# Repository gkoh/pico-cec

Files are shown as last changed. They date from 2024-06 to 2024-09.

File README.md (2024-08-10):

# Pico-CEC

A Raspberry Pi Pico based project to bridge HDMI CEC (Consumer Electronics
Control) and USB HID keyboard control (especially for use with Kodi).

Fully assembled Pico-CEC.

## Motivation

Micro/mini desktops are plentiful as second hand, budget friendly media players,
especially when installed with Kodi (eg. LibreELEC).
However, many of these devices do not support HDMI-CEC and require the user to
use additional peripherals (eg. wireless keyboard, game controller).

In this project we use a Pico to both:
* handle the CEC protocol on the HDMI port
* adapt the user control messages into USB keyboard inputs

## What Works
* HDMI CEC frame send and receive
* EDID parsing to determine HDMI physical address
* LibreELEC recognises Pico-CEC as an USB HID keyboard
* HDMI CEC basic user control messages are properly mapped to Kodi shortcuts,
  including:
   * navigations arrows
   * select
   * back
   * play
   * pause
   * numbers 0-9

## Cloning
To avoid cloning unneeded code, clone like this:
```
git -c submodule.active="lib/tinyusb" -c submodule.active=":(exclude,glob){lib,hw}/*" clone --recurse-submodules
```

Alternatively, clone everything in pico-sdk and tinyUSB:
```
git clone --recurse-submodules
```

## Building
This project uses the 'normal' CMake based build. To build the default image:
```
$ git clone <blah blah as above>
$ cd pico-cec
$ mkdir build && cd build
$ cmake ..
$ make
```

### Customising the Build
The CMake project supports three options:
* PICO_BOARD: specify variant of Pico board, defaults to Seeed XIAO RP2040
* CEC_PIN: specify GPIO pin for HDMI CEC, defaults to GPIO3

Example invocation to specify:
* use Raspberry Pi Pico development board
* use GPIO pin 11

```
$ cmake -DPICO_BOARD=pico -DCEC_PIN=11 ..
$ make
```

## Installing
Assuming a successful build, the build directory will contain `pico-cec.uf2`,
this can be written to the Pico as per normal:
* connect the Pico to computer via USB cable
* reset the Pico by holding 'Boot' and pressing 'Reset'
   * Pico now presents as a USB mass storage device
* copy `pico-cec.uf2` to the Pico
* disconnect

# Real World Usage
This is currently working with:
* a Sharp 60" TV (physical address 0x1000)
   * directly connected to TV HDMI input 1
* through a Denon AVR connected to the Sharp TV (physical address 0x1100)
   * Pico-CEC connected to Denon AVR HDMI input 1
   * Denon AVR connected to TV HDMI input 1
* a Sony 60" TV (physical address 0x1000)
   * directly connected to TV HDMI input 1

# Design
## Hardware
The hardware connections are extremely simple. Both HDMI CEC and the Pico are
3.3V obviating the need for level shifters. The DDC bus (for EDID) is I2C and
5V, however, the Pico appears to be 5V tolerant.

Additionally, we rely on the GPIO input/output impedance states to read or drive
the CEC bus. DDC is I2C requiring data and clock lines.
Thus, we need to directly connect four wires:
* HDMI CEC pin 13 direct to a GPIO
* HDMI CEC ground pin 17 direct to GND
* HDMI DDC clock pin 15 direct to SCL
* HDMI DDC data pin 16 direct to SDA

For the Seeed Studio XIAO RP2040:
* HDMI pin 13 --> D10
* HDMI pin 17 --> GND
* HDMI pin 15 --> D5
* HDMI pin 16 --> D4

### Schematic
Basic schematic.

After this we:
* connect `Pico-CEC` to the HDMI output of the PC
* connect the HDMI cable from the TV to `Pico-CEC`
* connect a USB cable from `Pico-CEC` to the PC

### Prototype

Initial prototype.

### Enclosure
The enclosure is a reasonably simple three piece sandwich 3d print modelled with OpenSCAD. It is designed to be printed as three separate pieces which are bolted together with M3 nuts and bolts.
An exploded preview of the result can be found in this [STL](openscad/pico-cec.stl).

### Assembly
XIAO RP2040 with HDMI pass through and DDC.

Partially assembled Pico-CEC.

## Software
The software is extremely simple and built on FreeRTOS tasks:
* cec_task
   * interact with HDMI CEC sending user control message inputs to a queue
* hid_task
   * read the user control messages from the queue and send to the USB task
* usbd_task
   * generate an HID keyboard input for the USB host
* blink_task
   * heart beat, no blink == no work

## cec_task
The CEC task comprises three major components:
* `recv_frame`
   * receives and validates CEC packets from the CEC GPIO pin
   * edge interrupt driven state machine
      * rewritten from busy wait loop to reduce CPU load
* `send_frame`
   * formats and sends CEC packets on the CEC GPIO pin
   * alarm interrupt driven state machine
      * rewritten from busy wait loop to reduce CPU load
* main control loop
   * manages CEC send and receive

All the HDMI frame handling was rewritten to be hardware/timer interrupt driven
to meet real-time constraints.
Attempts to increase the FreeRTOS tick timer along with busy wait loops were
simply unable to consistently meet the CEC timing windows.

## hid_task and usbd_task

These are simple FreeRTOS tasks effectively taken straight from the TinyUSB
examples.

## Dependencies
This project uses:
* FreeRTOS
* pico-sdk
   * tinyusb

# Hardware
* Seeed Studio XIAO RP2040 (chosen for form factor)
   * https://www.seeedstudio.com/XIAO-RP2040-v1-0-p-5026.html
   * Originally prototyped on the Raspberry Pi Pico board (still works with
     minor build time tweaks)
* HDMI male/female passthrough adapter
   * Listed as 'HDMI Male and Female Test Board MINI Connector with Board PCB
     2.54mm pitch 19/20pin DP HD A Female To Male Adapter Board'
   * Model number: WP-905
   * https://www.aliexpress.com/item/1005004791079117.html
* custom 3d printed housing

# Bill of Materials
| Component | Quantity | Price (June 2024) (AUD) |
| :--- | ---: | ---: |
| Seeed Studio XIAO RP2040 | 1 | 11.50 |
| HDMI male/female adapter | 1 | 4.30 |
| M3x10mm bolt & nut | 2 | 0.16 |
| M3x20mm bolt & nut | 2 | 0.17 |
| Random short wires | 2 | basically free |
| Scunge 3D print from friend | 1 | mostly free |
| Umpteen hours of engineering | 1 | priceless |
| Total | | 16.13 |

## Future
* more blinken LEDs
   * most Pico boards appear to have an RGB LED, use it
   * perhaps:
      * R - FreeRTOS crash handlers?
      * G - HDMI message received?
      * B - HID keyboard message sent?
* pass cec-compliance
   * https://docs.kernel.org/userspace-api/media/cec/cec-intro.html
* survive cec-compliance fuzzing
* port to ESP32?

# References
Inspiration and/or ground work was obtained from the following:
* https://github.com/SzymonSlupik/CEC-Tiny-Pro
* https://github.com/tsowell/avr-hdmi-cec-volume

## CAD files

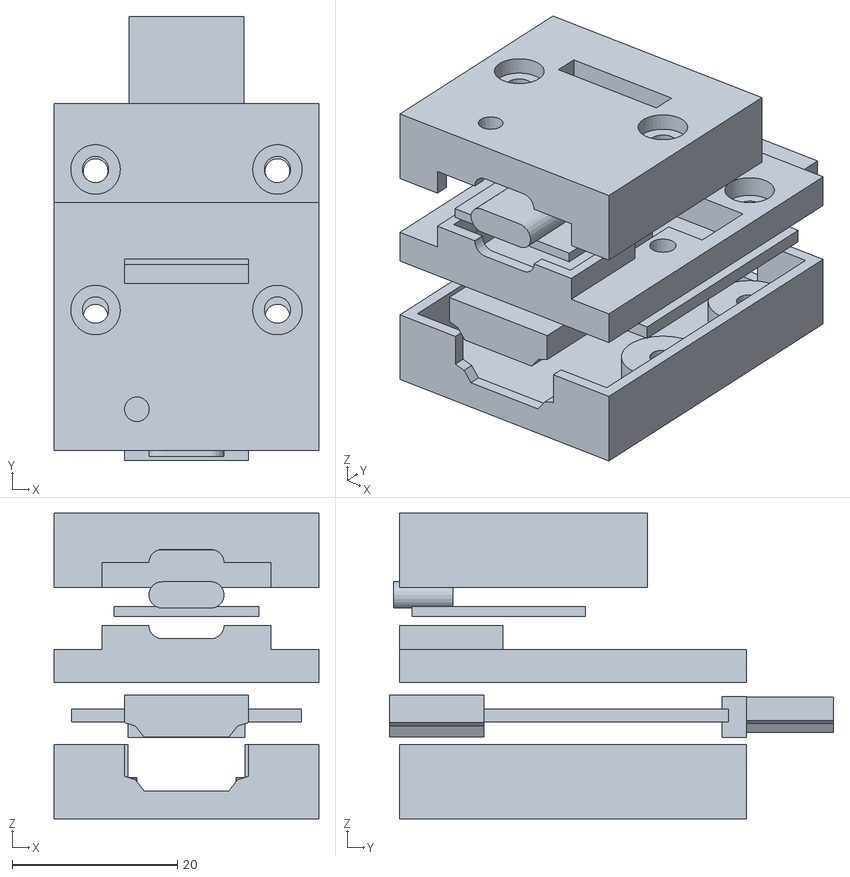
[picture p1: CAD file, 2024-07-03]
openscad/pico-cec.stl
32.0 x 53.7 x 37.0

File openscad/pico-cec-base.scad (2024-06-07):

include <pico-cec-lib.scad>

base();

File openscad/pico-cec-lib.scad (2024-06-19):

$fa = 1;
$fs = $preview ? 2 : 0.5;

module hdmi_2d_male() {
    union () {
        hull() {
            square([13.9, 2.8], true);
                translate([0,-(2.8+0.35)/2])
            square([11.45, 0.35], true);
        }
        hull () {
            translate([0,-(2.8+0.35)/2])
                square([11.45, 0.35], true);
            translate([0, -(4.45)/2])
                square([9.5, 1.3], true);
        }
    }
}

module hdmi_2d_female() {
    scale([15.0/13.9, 5.3/4.45])
        hdmi_2d_male();
}

module hdmi_male() {
    color("goldenrod") union() {
        linear_extrude(12.7)
            hdmi_2d_male();
        translate([0, -1, 12])
            cube([14.2, 5.0, 3],true);
    }
}

module hdmi_female() {
    color("red") linear_extrude(11.4)
        hdmi_2d_female();
}

module hdmi_adapter() {
    union() {
        color("green") difference() {
            cube([27.8, 29.6, 1.6], true);
            translate([11, (29.6/2) - 6, -1.5])
                cylinder(3, r=1.5);
            translate([-11, (29.6/2) - 6, -1.5])
                cylinder(3, r=1.5);
            translate([11, -((29.6/2) - 6), -1.5])
                cylinder(3, r=1.5);
            translate([-11, -((29.6/2) - 6), -1.5])
                cylinder(3, r=1.5);

        }
        translate([0, -(29.6/2), (4.45 - 2.8)/2])
            rotate([90, 0, 0])
                hdmi_female();
        translate([0, (29.6/2) + 12.7, (4.45 - 2.8)/2])
            rotate([90, 0, 0])
                hdmi_male();
    }
}

module usb_c_female() {
    color("silver") linear_extrude(7.2) {
        hull() {
            translate([4.55-1.6, 0, 0])
                circle(r=1.6);
            translate([-4.55+1.6, 0, 0])
                circle(r=1.6);
        }
    }
}

module xiao_rp2040() {
    union() {
        color("blue") cube([17.5, 21.0, 1.2]);
        translate([17.5/2, 5, 1.6+1.0])
            rotate([90,0,0])
                usb_c_female();
    }
}

module nut_m3() {
    cylinder(2.5, r=3.3, $fn=6);
}

module head_m3() {
    cylinder(2.5, r=3);
}

module base() {
    difference() {
        union() {
            difference() {
                cube([32, 40.5+1.5, 9], true);
                translate([0, 0, 1.5])
                    cube([32-3, 40.5+1.5-3, 9-1.5], true);
                translate([0, 4.1, 1.5])
                    hdmi_adapter();
                translate([0, 20, 5])
                    cube([14.1, 3, 3], true);
                translate([0, -20, 5])
                    cube([15.0, 3, 3], true);
            }
            // posts
            translate([11, 13.0, -4.5])
                cylinder(5, r=5);
            translate([11, -4.0, -4.5])
                cylinder(5, r=5);
            translate([-11, 13.0, -4.5])
                cylinder(5, r=5);
            translate([-11, -4.0, -4.5])
                cylinder(5, r=5);
        }
        // bolt
        translate([11, 13.0, -4.55])
            cylinder(5.1, r=1.6);
        translate([11, -4.0, -4.55])
            cylinder(5.1, r=1.6);
        translate([-11, 13.0, -4.55])
            cylinder(5.1, r=1.6);
        translate([-11, -4.0, -4.55])
            cylinder(5.1, r=1.6);
        // nuts
        translate([11, 13.0, -4.55])
            nut_m3();
        translate([11, -4.0, -4.55])
            nut_m3();
        translate([-11, 13.0, -4.55])
            nut_m3();
        translate([-11, -4.0, -4.55])
            nut_m3();
    }
}

module middle() {
    union() {
        difference() {
            cube([32, 40.5+1.5, 4], true);
            // bolt
            translate([11, 13.0, -2.55])
                cylinder(5.1, r=1.6);
            translate([11, -4.0, -2.55])
                cylinder(5.1, r=1.6);
            translate([-11, 13.0, -2.55])
                cylinder(5.1, r=1.6);
            translate([-11, -4.0, -2.55])
                cylinder(5.1, r=1.6);
            // head
            translate([-11, 13.0, -0.45])
                head_m3();
            translate([11, 13.0, -0.45])
                head_m3();
            // xiao rp2040 pins
            translate([7.5, -9.1, 0])
                cube([2.5, 21, 4.05], true);
            translate([-7.5, -9.1, 0])
                cube([2.5, 21, 4.05], true);
            // hdmi adapter pins
            translate([0, 4, 0])
                cube([27.8, 8, 4.05], true);
        }
        // usb-c port bottom half
        translate([0, -20.25, (4+2.9)/2])
            difference() {
                cube([20.5, 1.5, 2.9], true);
                translate([0, 5, 2.9/2 ])
                    rotate([90, 0, 0])
                        usb_c_female();
            }
         // side supports
         translate([-9.6, -14.5, (4+2.9)/2])
            cube([1.3, 12, 2.9], true);
         translate([9.6, -14.5, (4+2.9)/2])
            cube([1.3, 12, 2.9], true);
        }
}

module top() {
    difference() {
        cube([32,30, 9], true);
        translate([0, -2.5, -3])
            cube([32-3, 30-8.5, 9-3], true);
        translate([0, -13.25, -1.5 ])
            rotate([90, 0, 0])
                usb_c_female();
        translate([0, -14.05, -3])
            cube([20.5, 2, 3.05], true);
        // bolt
        translate([-11, 2, -0.5])
            cylinder(5.1, r=1.6);
        translate([11, 2, -0.5])
            cylinder(5.1, r=1.6);
        // head
        translate([-11, 2, 2.5])
            head_m3();
        translate([11, 2, 2.5])
            head_m3();
        // led/button slot
        translate([0, 6.7, 2.2])
            cube([15, 3, 5], true);
        // power led
        translate([-6, -10, -0.3])
            cylinder(5, r=1.5);
    }
}

//base();
//middle();
//top();

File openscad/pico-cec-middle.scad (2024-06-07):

include <pico-cec-lib.scad>

middle();

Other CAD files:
openscad/pico-cec-top.scad
openscad/pico-cec.scad

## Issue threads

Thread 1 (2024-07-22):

Not working with Sony TV

gkoh, 2024-07-22:
Pico-CEC works with a Sharp TV but isn't detected by a Sony TV.
Nothing happens when connected to HDMI port 1 and configured with physical address 0x1000.

Closed 2024-07-22.

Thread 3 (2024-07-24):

Add EDID parsing to determine physical address.

gkoh, 2024-07-24:
The HDMI physical address is available by parsing the EDID data blocks.
This requires adding two more pin connectors (SDA, SCL) to the HDMI DDC lines, these are:
* SDA: HDMI pin 16
* SCL: HDMI pin 15

These should be connected to the RP2040 thus:
* SDA: pin 6
* SCL: pin 7

The I2C bus for DDC is 5V, which is beyond the normal level of the Pico's 3.3V pins. However, directly connecting, despite the voltage difference, works successfully.

Closed 2024-07-26.

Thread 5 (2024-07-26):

Does not work with Samsung TV.

gkoh, 2024-07-26:
Pico-CEC is not detected by a Samsung TV.

Closed 2024-07-28.

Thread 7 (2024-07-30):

Buttons are impossible to access without tools

gkoh, 2024-07-30:
Although the buttons of the XIAO RP2040 are visible, the 3d housing prevents access without either:
* dismantling the enclosure
* using pointed tools (eg. toothpick, small screwdriver)

Possible solutions:
* modify enclosure to expose the buttons for finger pressing
   * remove part of the enclosure?
 * make a button extension thing as part of the enclosure
    * makes assembly a bit fiddly
 * something else?

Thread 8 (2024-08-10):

Display output disrupted on initial boot

gkoh, 2024-08-10:
On initial boot of a Dell Optiplex, the HDMI output is disrupted by `pico-cec`.
I suspect this is due to the DDC/EDID feature, as this didn't occur before.

It seems to be resolved by adding a small (5s) delay to the start of the HDMI CEC task.
This seems long enough for the PC BIOS to work out what display outputs are valid, without `pico-cec` disrupting the DDC traffic.

Closed 2024-08-10.

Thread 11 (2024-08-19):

Extract keymap to file.

dennizzzz, 2024-08-19:
Changing the key mappings requires recompilation. Extracting them to a file would make the system way more flexible.

Example:
```
00, Select, ENTER,
01, Up, ARROW_UP
02, Down, ARROW_DOWN
03, Left, ARROW_LEFT
04, Right, ARROW_RIGHT
0A, Options, C
0D, Exit, BACKSPACE
20, 0, 0
21, 1, 1
22, 2, 2
23, 3, 3
24, 4, 4
25, 5, 5
26, 6, 6
27, 7, 7
28, 8, 8
29, 9, 9
35, Display Information, I
44, Play, P
45, Stop, X
46, Pause, SPACE
48, Rewind, R
49, Fast Forward, F
51, Subtitle, L
```
Thoughts?

gkoh, 2024-08-20:
Interesting suggestion.
How would you envisage this working in:
* development
* installation

Note, this is an embedded system and there is no filesystem right now, so reading a file during runtime would require integrating more stuff.

dennizzzz, 2024-08-20:
> Note, this is an embedded system and there is no filesystem right now, so reading a file during runtime would require integrating more stuff.

My reference before this was a full RPi with Raspbian which has a Linux kernel, filesystems, Kodi and an integrated Pulse-Eight compatible(?) interface.

The absolute best option would be to embed a fat filesystem and a usb-driver and have the board present itself like a regular USB stick. Users write the configuration, including mapping, on it and the system reads it. This would take this project from the developer realm to the consumer realm and could make it a commercial product. (Making it fully Pulse-Eight compatible would also be a giant step in the that direction.)

But for now take a look at [littlefs](https://github.com/littlefs-project/littlefs) or something similar. I have used jffs(2) on my Asus router in the past, but that runs a beefy kernel and has a lot of flash.

gkoh, 2024-08-21:
@dennizzzz Thank you for the considered comment, appreciated.
OK, I think I understand your motivation, allow me to offer some thoughts.

> full RPi with Raspbian

Comparing to such a setup is misleading (but not incorrect). My 'other' HTPC is exactly this and indeed was my reference for what kind of 'experience' to replicate.

> fully Pulse-Eight compatible

The Pulse-Eight HDMI CEC hardware cost is what drove me to create this project. One should note however that it presents as a special USB device requiring driver installation to function. `pico-cec` was deliberately created to emulate an HID keyboard so it would be "plug'n'play", I would like to retain that.
Furthermore, I wonder about possible legal issues with mirroring a commercial product.

> the flexibility of configuration could even make it better

OK, I believe this is the real core of the issue.
Yes, it is inconvenient for an end user to install a full development environment because they want to map, say, 'red' button to the 'backspace'.
As you note, the useful configuration is just the mapping table, and we want to expose that. There are several options:
* present as a USB mass storage device, offer a virtual filesystem and a file defining the mapping
   * this is possible, we can create a virtual FAT filesystem and file and allow the user to edit said file
   * this solution is challenging, it opens up a lot of vectors for instability due to the 'free' nature:
      * user tries to format the device
      * user misconfigures the file
      * user uploads garbage
   * with no UI, we have no way to help the user correct the issue
      * not totally true, we could blink morse code on the LEDs
* present a serial console, offer a basic CLI to show and edit mapping
   * this seems the simplest, the user can open a serial terminal to `pico-cec` and is restricted by what they can do
   * the CLI doesn't need to be complex, all it needs is:
      * show - display the mappings
      * edit - edit/add a mapping entry
         * config can be validated
   * we have text UI now, we can report errors
   * this could even provide the ability to debug the CEC traffic or other aspects
* use a PicoW
   * everything is wifi enable these days
   * we could migrate to PicoW (or ESP32) and present a simple web UI
   * this costs more and requires wifi configuration (eg SSID, key, etc)

My order of preference and ease of implementation:
* USB serial interface
* Pico W + web UI
* USB mass storage + configuration file

Apologies for the long comment, it's a really interesting discussion.
Please let me know if I have misinterpreted anything.

dennizzzz, 2024-08-21:
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

How can MY reference be misleading? To flatten it: a box that work very well with HDMI-CEC.
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

:+1: :+1: :+1: The P8 is becoming rare and so the price is going up even more.

> One should note however that it presents as a special USB device requiring driver installation to function. `pico-cec` was deliberately created to emulate an HID keyboard so it would be "plug'n'play", I would like to retain that. Furthermore, I wonder about possible legal issues with mirroring a commercial product.

The device could be configured the HID-keyboard way (better for Windows) or the P8-driver-compatible way (better for Linux). If the P8 does not have a specific patent then there are no legal grounds for this.

> > the flexibility of configuration could even make it better
>
> OK, I believe this is the real core of the issue. Yes, it is inconvenient for an end user to install a full development environment because they want to map, say, 'red' button to the 'backspace'. As you note, the useful configuration is just the mapping table, and we want to expose that.

:+1:

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

Blink twice ... :smile: .

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

Yes, this could work very well with an ncurses interface. (You duplicated 'serial' here :smile: )

>
>     * Pico W + web UI

Different hardware, big :-1:,  and you would need to configure something to be able to configure something else. But once that is out of the way, writing complex web UI's is part of my day job.
>
>     * USB mass storage + configuration file

This would be easiest for the user, not the developer.

I would like to propose two more options:

1. A dedicated configuration application ("pico-cec-configurator" with a web UI?) that takes a compiled version of pico-cec, lets you configure everything and then flashes the entire thing.
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
gizmomelb, 2024-09-15:
ok found this article about writing to the flash - https://www.makermatrix.com/blog/read-and-write-data-with-the-pi-pico-onboard-flash/

gkoh, 2024-09-15:
> ok found this article about writing to the flash - https://www.makermatrix.com/blog/read-and-write-data-with-the-pi-pico-onboard-flash/

Thanks.
I have an offline branch with basic flash access, so this will certainly be the way forward.

RP2040 flash access requires interrupts to be disabled before access to prevent corruption.
To make it simple and robust I'm thinking to:
* store configuration in flash
* load configuration from flash into RAM during boot
* to reconfigure:
   * create a copy of the running configuration
   * allow user to modify said copy
   * when user saves changes, suspend everything, write copy to flash and require a reboot
      * the CEC task is completely IRQ driven and needs to be stopped before accessing flash

gkoh, 2024-09-15:
> FUTURE STUFF: As an aside - the VCC and GND pins on the underside of the Seeed XAIO RP2040 can be connected to HDMI pins 17 (GND) and 18 (+5V) to continuously power the RP2040 even when it is not drawing power from USB. This could be useful with some extra investigation I am doing with powering down the host pc and using WAKE ON LAN to start it back up - useful for the HDMI CEC power on / power off along with the TV and AVR etc.)

I did originally look into dual-power (VIN + USB-C) and it was unclear if the power protection was sufficient to prevent smoke. It will interesting to see what you find.

Responding to CEC 'power on' actually adds a third category of command mapping, so the three are now:
* User Control buttons (eg. navigation, numbers, etc)
* Vendor Command (#14)
* HDMI CEC 'primary' messages, eg:
   * on CEC 'Standby' send keystroke to suspend PC

gizmomelb, 2024-09-15:
also having even a basic checksum when saving / loading the config will help avoid any corruptions.  I'm not an experienced programmer but I'm willing to have a go, especially the stuff outside of the main loop.  That way I hopefully can't stuff up too easily :)

dennizzzz, 2024-09-15:
@gizmomelb
> Therefore we need to be able to store the (eventually) user defined key presses somehow on the RP2040 without it being encoded into the compiled uf2 file - so the file needs to either be able to be stored in the 2MB FLASH on the RP2040, OR needs to be accessible another way on boot (without the RP2040 being connected to a PC) if the RP2040 loses power by being unplugged or the host device being switch off etc.

There still has to be a statically compiled default/base configuration.

Reading about wear and tear of flash memory, I suggest we split up what we write into:
- A, an address block of 256B and the last block of flash memory. This will be written on first initialization and then only when C gets corrupted.
- C, a configuration block of 8KB, let's assume the complete configuration will fit in that. It will be located just before A or any previously corrupted configuration blocks.

Upon booting pico-cec reads A to get the address of C. A should start with a 4 byte magic number to identify it as an address block. If A does not have the magic number we do not read C and we revert to the statically compiled configuration. If A does have the magic number we parse the configuration from C. When we change the configuration it gets prepared for writing to C, a CRC is calculated and put at the end. When the configuration is written to C, we read back C but NOT as configuration, recalculate the CRC, and match with the previously written CRC. If the CRC does not match then C is corrupt, A will be changed to point to an 8KB lower address to a new C and the prepared configuration block will be written to C and rechecked with CRC. Two(?) consecutive write fails indicates flash failure. How to deal with that?

> If we can read the config file from RP2040 FLASH, then serial over USB is fine for storing the config file on the RP2040. However if we cannot easily store the config file in the flash, then may I suggest using SPI and an SD CARD as a way for the RP2040 to read the config file at boot time?

No. The pico-cec needs to work stand-alone. So we don't read/write a file, we read/write blocks of flash. The way flash works does impact the flow of pico-cec. We can't record a button and write it to flash immediately. We need to record all the buttons to RAM and then write the configuration as a single block. Other than that your suggested loop looks reasonable.

 I also think that there should be something like the [Konami
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

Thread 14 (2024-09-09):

Add support for vendor commands.

gkoh, 2024-09-09:
Originally mentioned by @gizmomelb here:
https://github.com/gkoh/pico-cec/issues/11#issuecomment-2327639912_

Vendor commands, as far as I understand, are not strictly defined.
A single vendor command appears limited to 14 bytes, which helps.

However, I haven't seen enough of them to know how to handle them in a configurable way.
Experience with other embedded protocols suggests the following:
* it is likely we will need to reverse engineer the contents of the command
* commands may:
   * expect a specific response
   * expect no response

The first cut should just support hardcoded commands and responses ie.:
* if receive <this exact vendor command>
* reply <this exact response> OR
* do something else?

Once we get here, we should be able to gain more data to make better informed design choices.

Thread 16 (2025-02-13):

RokuTV weird behaviour after turning TV off and back on

workingmanrob, 2025-02-13:
Hey!  First of all thanks for this project.  Amazing stuff.

I am still waiting for my seeed boards to arrive but in the meantime I did build a regular pico "prototype" and I do have it working but it requires jumping through a few hoops to get kodi comms up and running.

What I believe I am seeing is the Roku doing CEC detection when the TV powers on and the device does not report CEC capable or maybe just active input..?

My workaround to get the TV remote talking to kodi involves a little input hot swapping.

TV has kodi on HDMI1 and a chromecast on HDMI3.

TV menu reports HDMI3 is a CEC device but not HDMI1.

So with the PC powered and kodi running I swap the chromecast to HDMI1 then in the TV menu run the update CEC device scan which then sees the chromecast on HDMI1.

Then I switch to the HDMI1 input and hot swap out the chromecast for my kodi PC.

Kodi works great at this point until anything is turned off or even TV switches inputs.

I see a closed issue #6 about Samsung TV which sounds similar.

Can load the debug build and dump what it sees over serial if that's helpful at all just lmk!

But thanks again for this.  The hope of one remote to rule them all lives once again..

gkoh, 2025-02-13:
@workingmanrob Thanks for raising an issue!

Hmm ... I think you're right, #6 was all about weird CEC detection and that certainly seems the case here.

A few questions:
* does this happen if the chromecast is not connected?
   * ie. if kodi is the only HDMI source?
   * there is a hardcoded delay in pico-cec before it does it's HDMI address query
      * it's possible this is colliding with the chromecast also doing the query
* are you comfortable with compiling the project from source?
   * not a requirement, but might help with deeper debug
   * we could possibly hardcode the HDMI address to see if that fixes the issue

workingmanrob, 2025-02-13:
Hi @gkoh

Thanks for the quick reply.. I did take a moment to try the debug build - I did build this from source - and got the following:

```
00 -> 0f: [Request Active Source]
00 -> 0f: [Request Active Source]
00 -> 0f: [Request Active Source]
00 -> 0f: [Request Active Source]
08 -> 00: [Give Device Power Status]
<-- 08:90 [Report Power Status]
08 -> 00: [Give Device Power Status]
<-- 08:90 [Report Power Status]
00 -> 08: [Report Power Status]
00 -> 08: [Report Power Status]
```
after the hot swap magic...
```
00 -> 04: [User Control Pressed]User Control Up
00 -> 04: [User Control Released]
00 -> 04: [User Control Pressed]User Control Down
00 -> 04: [User Control Released]
00 -> 04: [User Control Pressed]User Control Left
00 -> 04: [User Control Released]
04 -> 00: [Give Device Power Status]
<-- 04:90 [Report Power Status]
00 -> 04: [Report Power Status]
00 -> 04: [User Control Pressed]User Control Right
00 -> 04: [User Control Released]
00 -> 04: [User Control Pressed]User Control Select
00 -> 04: [User Control Released]
00 -> 04: [User Control Pressed]User Control Select
00 -> 04: [User Control Released]
```
I am willing to hard code addresses like an animal... 😉

Will give the kodi on it's own test a try right now.  I just need to switch the pico back  to the normal build first.

workingmanrob, 2025-02-13:
hmmm so.. I reverted to the normal build I have that works.  Kodi control was fine.

As soon as I unplugged the chromecast - from HDMI3 - pico-cec stopped working.

My mini PC was the only thing connected - to HDMI1.  Rebooting the TV and the PC made no difference.

Where would I find this address to hard code?  Also where do I hard code that..?  Very willing to take the plunge.

Thanks again!

gkoh, 2025-02-14:
> I did build this from source

Brilliant, I always appreciate having someone go that slight extra step.

> hmmm so.. I reverted to the normal build I have that works. Kodi control was fine.
> As soon as I unplugged the chromecast - from HDMI3 - pico-cec stopped working.
> My mini PC was the only thing connected - to HDMI1. Rebooting the TV and the PC made no difference.

Hmm indeed, that is weird and certainly sounds like pico-cec and the RokuTV aren't negotiating right.

> Where would I find this address to hard code? Also where do I hard code that..? Very willing to take the plunge.

This is a good first step to see if the auto-address stuff is the problem.
On this line:
https://github.com/gkoh/pico-cec/blob/b5b7028e7cc7a8e73e536d468b3fd10ccb5ff4d4/src/hdmi-ddc.c#L146
replace with `address = 0x1000;` or whichever address you choose.

CEC addressing is a 16 bit system, where each set of 4 bits dictates the location in the tree.
In almost all configurations the TV (or primary display) is always `0x0000`.
The HDMI ports of the TV are usually enumerated as:
* HDMI1 = `0x1000`
* HDMI2 = `0x2000`
* HDMI3 = `0x3000`
* etc

If you had, say, an AV system on HDMI1 (0x1000) and it had its own HDM1 port, that would be 0x1100.
With this you can nest HDMI devices to 4 levels deep, for example:
* TV (0x0000) -> AV1 (0x1000) -> AV2 (0x1100) -> AV3 (0x1110) -> Kodi (0x1111)
and each level can up to 16 (15?) devices.

In your case, if kodi is on HDMI1 of the RokuTV, I think `0x1000` is a good start.
You could also try `0x3000` and plug it in HDMI3 to experiment.

There is another layer on top of this, the 'logical address', which could also be the problem. We can explore that depending on what you find with hard coding the physical address.

gkoh, 2025-02-14:
Just looking at your logs more closely.

This says it got logical address 8, which is "Playback Device 2".
```
08 -> 00: [Give Device Power Status]
```

and after the hotswap magic:
```
04 -> 00: [Give Device Power Status]
```
which is "Playback Device 1".
These both look correct, assuming the chromecast was first and picked up address 4.
I think this works because the chromecast has done 'the right thing' to activate this port somehow.

I'd wager that the hardcoded physical address won't help and that the RokuTV is expecting some kind of response early in the negotiation.
Chances are we will need to put pico-cec into monitor/sniff mode to see how the TV interacts with the chromecast and replicate that behaviour.

workingmanrob, 2025-02-14:
Well that's a bunch of very useful info!

But yes, sadly, even with the hardcoded address it's doing the same as before.. 😦

With just the PC the debug build prints
```
00 -> 0f: [Request Active Source]
00 -> 0f: [Request Active Source]
```
when I press any button.  Couldn't have been that easy... darn.

My suspicion is the TV probes inputs whenever it wakes - or switches inputs - and it's not getting a CEC handshake or whatever it's expecting so it does no CEC on that input.

When I trick that input with my hot swap to just enable CEC on it then it starts sending stuff the pico wants to see and the debug output is exactly what we would expect...
```
00 -> 04: [User Control Pressed]User Control Down
00 -> 04: [User Control Released]
00 -> 04: [User Control Pressed]User Control Up
00 -> 04: [User Control Released]
00 -> 04: [User Control Pressed]User Control Left
00 -> 04: [User Control Released]
00 -> 04: [User Control Pressed]User Control Right
00 -> 04: [User Control Released]
00 -> 04: [User Control Pressed]User Control Down
00 -> 04: [User Control Released]
00 -> 04: [User Control Pressed]User Control Pause
00 -> 04: [User Control Released]
```
So at least it does work with the chromecast disconnected.

And how would I put this doodad into sniffer mode??  I am learning so much! 😀

Thanks again

workingmanrob, 2025-02-14:
And it occurred to me that I could probably just wire that up with the chromecast feeding the pico and watch the debug build print out a bunch of stuff.  It did!
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

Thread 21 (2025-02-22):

cec-compliance

gkoh, 2025-02-22:
With the updated CLI and `debug on` mode, it has become _significantly_ easier to rapidly develop and test.
Additionally, having a spare Raspberry Pi enables cec-compliance testing.

Following are the outputs for a series of `cec-compliance` test sets:

### `--test-core`
```
testing CEC local LA 1 (Recording Device 1) to remote LA 4 (Playback Device 1):
	Core:
	    Feature aborts unknown messages: FAIL
	    Feature aborts Abort message: FAIL

	Post-test checks:
	    Recognized/unrecognized message consistency: OK
```

### `--test-system-information`
```
testing CEC local LA 1 (Recording Device 1) to remote LA 4 (Playback Device 1):
	Core:
	    Feature aborts unknown messages: OK
	    Feature aborts Abort message: OK

	System Information feature:
	    Polling Message: OK
	    Give Physical Address: OK
	    Give CEC Version: OK
	    Get Menu Language: OK (Not Supported)
	    Set Menu Language: OK (Presumed)
	    Give Device Features: OK (Not Supported)

	Post-test checks:
	    Recognized/unrecognized message consistency: OK
```

### `--test-capability-discovery-and-control`
```
testing CEC local LA 1 (Recording Device 1) to remote LA 4 (Playback Device 1):
	Core:
	    Feature aborts unknown messages: OK
	    Feature aborts Abort message: OK

	Capability Discovery and Control feature:
	    CDC_HEC_Discover: OK (Not Supported)

	Post-test checks:
	    Recognized/unrecognized message consistency: OK
```

### `--test-device-menu-control`
```
testing CEC local LA 1 (Recording Device 1) to remote LA 4 (Playback Device 1):
	Core:
	    Feature aborts unknown messages: OK
	    Feature aborts Abort message: OK

	Device Menu Control feature:
	    Menu Request: OK (Not Supported)
	    User Control Pressed: OK (Presumed)
	    User Control Released: OK (Presumed)

	Post-test checks:
	    Recognized/unrecognized message consistency: OK
```

gkoh, 2025-02-22:
After invoking a `--test-fuzzing` run for about 10 minutes, `pico-cec` is still standing.
The test runs forever until an error occurs, so I will let it go for 'a bit longer'.

gkoh, 2025-02-22:
> After invoking a `--test-fuzzing` run for about 10 minutes, `pico-cec` is still standing. The test runs forever until an error occurs, so I will let it go for 'a bit longer'.

1 hour of fuzzing, no crashes.
Although the serial output got spammed with a single character 3 times.
I don't know what sequence caused this, this will require careful investigation.

gkoh, 2025-02-22:
After fixing the core compliance, a full test run results in three failures:
```
		fail: cec-test-audio.cpp(960): status != CEC_OP_SYS_AUD_STATUS_OFF
	    System Audio Mode Request (off): FAIL
```
```
		fail: cec-test.cpp(507): !timed_out(&msg)
	    Request Active Source: FAIL
	warn: cec-test.cpp(475): Expected Active Source or Set Stream Path reply to Inactive Source
	    Inactive Source: OK (Unexpected)

```
```
	Standby/Resume and Power Status:
		>>> Sending Standby message.
		>>> Waiting for new stable power status. This may take up to 60 s.
		fail: cec-test-power.cpp(347): !poll_stable_power_status(node, me, la, CEC_OP_POWER_STATUS_STANDBY, unresponsive_cnt)
	    Standby: FAIL
```

gkoh, 2025-02-23:
v0.2.2 now passes cec-compliance.

Closed 2025-02-23.

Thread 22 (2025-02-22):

cec-compliance 'test-core' fails

gkoh, 2025-02-22:
As per #21, `pico-cec` is failing the core test.

### `Feature aborts unknown messages: FAIL`
The HDMI specification says:
* on broadcast, ignore
* on directed, send a 'feature abort' message

### `Feature aborts Abort message: FAIL`
The specification indicates this is a test message.
* on broadcast, ignore
* on directed, send 'feature abort message'

Closed 2025-02-22.

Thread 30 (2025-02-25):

Add RGB LED status indicators

gkoh, 2025-02-25:
The Seeed XIAO RP2040 includes an RGB LED that would prove useful as an easy visual status indicator.
As of now, there are two active LEDs:
* power LED
* blue blink LED

I am considering:
* green blink (1Hz): CEC active
   * for cec-compliance, we now track power status, thus easy to do
* blue flash: key press
   * too much blue?
* red flashing:
   * 2Hz = whole system crash
   * 1Hz = other crash?
      * not sure if this is useful/possible
      * most crashes result in whole system crash

@LaserBearIndustries does the above meet your requirements?

If the blink task were slightly improved, we can use FreeRTOS's direct to task notifications for robust inter-task communications.
This would allow adding a 'status change' request API that can be called anywhere in the system.
FreeRTOS includes a system crash handler for the red flashing.

Also need to review the blink task stack size, it was originally sized for doing almost nothing, which will be much less true.

As implemented by @LaserBearIndustries in the [CEC-Enabler](https://github.com/LaserBearIndustries/CEC_Enabler) fork, PIO seems to be the simplest way to get WS2812 support without further custom development.

LaserBearIndustries, 2025-02-25:
Those are perfect, I went a little dim on my WS2812 outputs to keep it from being too distracting. Just a crash of the system or disconnect from the TV if possible. I like moving to freeRTOS for the LED control.  My hacky method using a shared variable was just a quick change to get it working.

gkoh, 2025-02-25:
> Those are perfect, I went a little dim on my WS2812 outputs to keep it from being too distracting. Just a crash of the system or disconnect from the TV if possible. I like moving to freeRTOS for the LED control. My hacky method using a shared variable was just a quick change to get it working.

Excellent!
I will incorporate most of the LED changes (including the RED boot state) from the CEC-Enabler branch.
Happy to retain your WS2812 palette, these LEDs need to be indicative, not blinding.

gkoh, 2025-02-26:
This has landed as:
* blue 2Hz: idle, CEC standby
* green 2Hz: CEC active
* green flash: CEC user button pressed
* solid red: stack overflow

I oversold the FreeRTOS crash handling, there is really only the stack overflow detection, which in itself is 'best effort'. Even access to timers after stack corruption is iffy, so I've opted for the most basic, light it red.

I retained the blink frequency at 2Hz, 1Hz was too exciting 🙂

pico-sdk includes supports for the pin definitions of many boards, including the Seeed XIAO RP2040 and Waveshare RP2040-Zero.

It should be straightforward to either:
* change the 'PICO_BOARD' build variable when invoking cmake
* OR modify the CMakeLists.txt to suit

LaserBearIndustries, 2025-02-26:
I ran into an issue, the RP2040-Zero does not have a regular led so there
is no definition for the default led pin, I added an ifndef declaration to
blink and extern the variable which was able to get past that. I am also
having problems with CEC connecting now, I am looking into it to see what
is happening, so far tested on a Samsung and an Insignia TV at my office.

In the serial console I see this
Failed to write DDC reset: generic
[    153581] 00 <~ 04: [Image View On]

when I query EDID I get this error
Failed to write DDC reset: generic
Physical address : 0x0000
Looks like the same error.

Doesn't go green,

Resetting CEC on the TV shows this in debug mode
[    363254] 00 ~> 01: [Polling Message]
[    363295] 00 ~> 01: [Polling Message]
[    363336] 00 ~> 02: [Polling Message]
[    363377] 00 ~> 02: [Polling Message]
[    363419] 00 ~> 03: [Polling Message]
[    363459] 00 ~> 03: [Polling Message]
[    363501] 00 -> 04: [Polling Message]
[    363541] 00 -> 04: [Polling Message]
[    363583] 00 ~> 05: [Polling Message]
[    363624] 00 ~> 05: [Polling Message]
[    363665] 00 ~> 06: [Polling Message]
[    363706] 00 ~> 06: [Polling Message]
[    363748] 00 ~> 07: [Polling Message]
[    363789] 00 ~> 07: [Polling Message]
[    363830] 00 ~> 08: [Polling Message]
[    363872] 00 ~> 08: [Polling Message]
[    363914] 00 ~> 09: [Polling Message]
[    363955] 00 ~> 09: [Polling Message]
[    363997] 00 ~> 0a: [Polling Message]
[    364038] 00 ~> 0a: [Polling Message]
[    364079] 00 ~> 0b: [Polling Message]
[    364120] 00 ~> 0b: [Polling Message]
[    364162] 00 ~> 0c: [Polling Message]
[    364203] 00 ~> 0c: [Polling Message]
[    364245] 00 ~> 0d: [Polling Message]
[    364286] 00 ~> 0d: [Polling Message]
[    364327] 00 ~> 0e: [Polling Message]
[    364369] 00 ~> 0e: [Polling Message]
[    364482] 00 ~> 0f: [Set Stream Path]
[    368313] 00 ~> 0f: [Routing Change]
Issuing DDC reset
Failed to write DDC reset: generic
[    368380] 00 <~ 04: [Image View On]
[    368574] 00 ~> 0f: [32] (undecoded)

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

LaserBearIndustries, 2025-02-26:
Ok, figured it out. Looks like the WS 2040zero board defaults to I2C 1 on
pins 6/7 instead of I2C 0 on pins 4/5, I am working on a custom board
definition as a workaround since my PCBs are already made on this.

On Wed, Feb 26, 2025 at 11:13 AM Business Bear ***@***.***>
wrote:

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

LaserBearIndustries, 2025-02-26:
Made my own board definition and now it passes without needing to change
anything in the base code, thanks for all the help with this. If you would
like, I can set you up as an affiliate and you can get payment for a
promoted link if someone buys a dongle from our store, they would get a
small discount and you would get a portion of the sale.

On Wed, Feb 26, 2025 at 12:35 PM Business Bear ***@***.***>
wrote:

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
>>> This has landed as:
>>>
>>>    - blue 2Hz: idle, CEC standby
>>>    - green 2Hz: CEC active
>>>    - green flash: CEC user button pressed
>>>    - solid red: stack overflow
>>>
>>> I oversold the FreeRTOS crash handling, there is really only the stack
>>> overflow detection, which in itself is 'best effort'. Even access to timers
>>> after stack corruption is iffy, so I've opted for the most basic, light it
>>> red.
>>>
>>> I retained the blink frequency at 2Hz, 1Hz was too exciting 🙂
>>>
>>> pico-sdk includes supports for the pin definitions of many boards,
>>> including the Seeed XIAO RP2040 and Waveshare RP2040-Zero.
>>>
>>> It should be straightforward to either:
>>>
>>>    - change the 'PICO_BOARD' build variable when invoking cmake
>>>    - OR modify the CMakeLists.txt to suit
>>>
>>> —
>>> Reply to this email directly, view it on GitHub
>>> <https://github.com/gkoh/pico-cec/issues/30#issuecomment-2683623386>,
>>> or unsubscribe
>>> <https://github.com/notifications/unsubscribe-auth/BBI6X33NIR6T6LITURDI7XL2RUGGNAVCNFSM6AAAAABXZQ62ZWVHI2DSMVQWIX3LMV43OSLTON2WKQ3PNVWWK3TUHMZDMOBTGYZDGMZYGY>
>>> .
>>> You are receiving this because you were mentioned.Message ID:
>>> ***@***.***>
>>> [image: gkoh]*gkoh* left a comment (gkoh/pico-cec#30)
>>> <https://github.com/gkoh/pico-cec/issues/30#issuecomment-2683623386>
>>>
>>> This has landed as:
>>>
>>>    - blue 2Hz: idle, CEC standby
>>>    - green 2Hz: CEC active
>>>    - green flash: CEC user button pressed
>>>    - solid red: stack overflow
>>>
>>> I oversold the FreeRTOS crash handling, there is really only the stack
>>> overflow detection, which in itself is 'best effort'. Even access to timers
>>> after stack corruption is iffy, so I've opted for the most basic, light it
>>> red.
>>>
>>> I retained the blink frequency at 2Hz, 1Hz was too exciting 🙂
>>>
>>> pico-sdk includes supports for the pin definitions of many boards,
>>> including the Seeed XIAO RP2040 and Waveshare RP2040-Zero.
>>>
>>> It should be straightforward to either:
>>>
>>>    - change the 'PICO_BOARD' build variable when invoking cmake
>>>    - OR modify the CMakeLists.txt to suit
>>>
>>> —
>>> Reply to this email directly, view it on GitHub
>>> <https://github.com/gkoh/pico-cec/issues/30#issuecomment-2683623386>,
>>> or unsubscribe
>>> <https://github.com/notifications/unsubscribe-auth/BBI6X33NIR6T6LITURDI7XL2RUGGNAVCNFSM6AAAAABXZQ62ZWVHI2DSMVQWIX3LMV43OSLTON2WKQ3PNVWWK3TUHMZDMOBTGYZDGMZYGY>
>>> .
>>> You are receiving this because you were mentioned.Message ID:
>>> ***@***.***>
>>>
>>

gkoh, 2025-02-26:
> Made my own board definition and now it passes without needing to change
> anything in the base code, thanks for all the help with this.

That's great!
This is definitely the right solution.

I admit I completely forgot to even build the `waveshare_rp2040_zero` variant 😐
I will rectify this by adding some CI targets.

> If you would like, I can set you up as an affiliate and you can get payment for a
> promoted link if someone buys a dongle from our store, they would get a
> small discount and you would get a portion of the sale.

Oh wow, this is beyond generous.
I will politely decline as it was never my intent to make money from this.

LaserBearIndustries, 2025-02-26:
No worries at all, I just wanted to offer it in case that was something you
would want to do. I should be able to send you one of the dongles on
Friday, I wanted to switch to black screws so they don't stick out as much
on the assembled unit. The stainless steel ones I originally ordered just
look out of place on the black shells.

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

gkoh, 2025-02-27:
> No worries at all, I just wanted to offer it in case that was something you
> would want to do.

No problems, I truly appreciate the offer.
If you're really keen, I'm happy to take a donation via the github sponsor system:
https://github.com/sponsors/gkoh

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

That's 100% fine. I don't even need the cables 🙂

Closed 2025-02-26.

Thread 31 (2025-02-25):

Add keymap 'default' setting

gkoh, 2025-02-25:
The keymap is now stored in NVS.
However, with the current system, there is no way to differentiate between:
* default initial keymap stored in NVS
* custom keymap stored in NVS

In particular:
* if a user never customises the keymap
* AND the default keymap changes (eg. a new mapping is added)
* AND the new version of `pico-cec` is installed
* the user will not get the new default keymap without using the CLI

The fix is:
* add a boolean to the setting: custom keymap or not
* set this to 'not' as default
* set this to 'not' if `set keymap kodi` is called
* set this to 'yes' in the non-existent keymap command
* update the settings version number
   * handle the version migration

Closed 2025-02-26.

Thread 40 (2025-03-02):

Suggestion: Use Pico PIOs?

iso2013, 2025-03-02:
Hey, I love the project. Coincidentally, I was looking into implementing the CEC protocol myself on a Pi Pico just a few months ago--I don't like the restrictions that libcec puts in place and want to be able to tinker with and view the raw packets. One idea I had is to use the Pico's PIO modules. Is that something you'd be interested in working on together? (If that's even possible? I'm not overly experienced with the PIOs but I think it could be a really cool way to free up the main CPU.)

gkoh, 2025-03-02:
@iso2013

> Hey, I love the project.

👍

> Coincidentally, I was looking into implementing the CEC protocol myself on a Pi Pico just a few months ago ...

Also coincidentally, there was a discussion raised on exactly this topic recently: #15

Originally, I wanted to ensure the code was platform agnostic, but if we preserve the existing interrupt driven state machine (and maintain the intermediate frame handling API, then it can remain portable).
In fact, as the existing C version is now known 'stable', it's a good reference implementation.

That's a fairly long winded way to yes, I would be interested in helping to implement a PIO version of the CEC frame handling.
Bear in mind:
* we just ate a PIO with WS2812 support, that leaves 3 PIO SMs
* my original investigation and attempt strongly suggest RX and TX cannot both fit in 32 instructions
   * TX and RX will likely need to be hotswapped
      * I'm happy to be proven very wrong here!
* I'd like TX and RX to retain the ability to detect and handle on erroneous behaviour

TX would be a good place to start!
(actually the PIO in #15 could be good starting point)

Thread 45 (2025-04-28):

Case for original pico?

workingmanrob, 2025-04-28:
Hey again gkoh!

I was going to make a few more of these when parts arrive but I want to use the original pico boards instead of the seeed version.  The original is cheaper and easier to source locally for me.

Took a kick at modding the case you provided to learn I am pretty awful at openSCAD but I did make some progress.  I then tried to change the usb-c connector to micro and I had to walk away from my computer for a bit...

Kind of hoping you have already tried to make a case for the original that you could share.  If not I'm happy to learn openSCAD but I'd also take any pro tips you can share.

Thanks again!! 🍻

gkoh, 2025-04-29:
Ahaha ...
OpenSCAD was an experiment, it was my first time using it and I though the idea of '3d model as code' was intriguing.
That was the only advantage, because actually making the model was a head-banging exercise, so, apologies for that.
If I had my time again, I might try FreeCAD or similar.

The case was the last step, after I'd identified the hardware, form factor and stuff, unfortunately I do not have anything suitable for the original Pico dev board.

If you want to persist with OpenSCAD, my only suggestion is to model in, uh, negative space, especially for the ports.
By that I mean:
* model the actual port itself
* then subtract it from the case
   * possibly with a tiny multiplier as tolerance

I found it most efficient to model the 'inserts' then the solid bits, then subtract them.

There are some OpenSCAD part libraries that may be helpful? (I couldn't find any when I started).

Hope this helps!

workingmanrob, 2025-04-30:
OK maybe I'll experiment with FreeCAD...

I was starting to wrap my head around things and made a pico board insert that should have been the right dimensions but my attempt at the micro usb nearly melted my brain.

Lots of time still before the HDMI boards show up so I'll keep at it and if I make anything worth sharing I'll pass it along.

Cheers 🍻

gkoh, 2025-05-02:
> OK maybe I'll experiment with FreeCAD...

FreeCAD isn't straightforward either 😐
I apologise for foisting an experiment with OpenSCAD onto you.
I'd be 100% OK if you have better CAD tools or an STL to offer.

> I was starting to wrap my head around things and made a pico board insert that should have been the right dimensions but my attempt at the micro usb nearly melted my brain.
>
> Lots of time still before the HDMI boards show up so I'll keep at it and if I make anything worth sharing I'll pass it along.

👍
Lemme know if you make progress or have a branch, happy to have a look.

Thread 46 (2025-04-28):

2012 macbook pro no CEC control

workingmanrob, 2025-04-28:
Here I am again... back for more 😄

Booted libreElec 12.0.2 on a 13" MBP9,2 and had no CEC control.

Using the same pico and libreElec build on a 15" MBP11,4 and everything works as expected.

Will compile more info after I switch back to the 13".

I can say the 13" uses a mini display port to HDMI doodad while the 15" had a direct HDMI output.

Thanks gkoh!

workingmanrob, 2025-04-28:
The problem happens on the 15" as well when I use the mini DP to HDMI.. might be case closed already.  Need to dig up some other cables to test further.

workingmanrob, 2025-04-28:
The only other thing I have is a thunderbolt dock which has an HDMI output and a second thunderbolt/miniDP port.

HDMI port works but miniDP does not.  No other cables to test with so I'm closing this as a hardware/adapter issue.

Cheers! 🍻

gkoh, 2025-04-29:
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

Thanks for chasing it through.
From my quick glance, DP and miniDP don't officially support CEC and it's up to the adapters to pass through the pin.

I have a working setup which does DP->HDMI, where the adapter just passes all the pins through, so it is technically possible.

workingmanrob, 2025-05-04:
I didn't really want to comment on my closed issue but I am a bit confused as I shop around for another miniDP adapter..

Why does DP need to support CEC at all?

TV sends CEC to pico - pico converts to USB keyboard presses - I rejoice.

At least that's how I imagine it all goes down but then it doesn't and I am disappointed.. this is where I'm obviously mistaken in my assumptions of how this all works.

Any suggestion on miniDP to HDMI.. not seeing products that even mention CEC when listing features.

TIA 🍻

workingmanrob, 2025-05-06:
Thanks for the tips!

I can say this el cheapo mabob is not working.

- https://www.primecables.ca/p-308367-ada-5311-primecables-mini-displayport-thunderbolt-to-hdmi-female-adapter-cable-with-audio-support

I tried a few wiring variations but the only messages I see on the debug console..
```
> debug on
[     48665] 00 ~> 00: [Polling Message]
[     48785] 00 ~> 00: [Polling Message]
[     48855] 00 ~> 00: [Polling Message]
[     48977] 00 ~> 00: [Polling Message]
```
🤷‍♂

gkoh, 2025-05-07:
> Thanks for the tips!

👍

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

Hmmm.
I just realised that there is some electrical debug we could perform, assuming you have a multimeter.
If you have an available HDMI pass through test adapter, we can check what's happening with pin 13.
There are 3 possibilities:
* macbook ties pin 13 to ground
* adapter ties pin 13 to ground
* pin 13 is free (and thus should work)

And there is the brute force solution, cut the track on the HDMI pass through test adapter.
Depending on your soldering and/or knife skills, you could physically disconnect HDMI pin 13 on the Macbook side.
And if that still doesn't work:
* we've wasted an adapter
* there is something else at play

workingmanrob, 2025-05-08:
Dammit I just put my multimeter away after a happy day of hacking cables.. I'll dig it back out.

Just got my fresh batch of 3 HDMI pass through mabobs today so I prepared one to use with the only pico I have left which is the original raspberry pi pico.  Had to pull fresh and compile again using PICO_BOARD=pico but that failed with a WS2812 pin message... so I cheesed it and said use pins 14 and 15 for that and now I have a uf2 file to try.

Not shy to fire to up the iron or slice and dice it up a bit.

It is pushing 2am here now though so I'm not going down that rabbit hole tonight.

Will ping back when I have a chance tomorrow to poke around.

PS - made some progress on the case for standard pico but I have also decided I'm going to chop the end of the pico off with a saw - https://www.hackster.io/news/phillip-burgess-hacks-a-raspberry-pi-pico-down-to-size-literally-sawing-off-the-bottom-quarter-d8478eecfb49 - so it will fit in the case

workingmanrob, 2025-05-08:
So I did a quick test and continuity says pin 13 is not tied to ground but I only have the original pico to play with right now and am not having much luck getting a working build.

Backing up to solder some longer wires to the HDMI board but I also did figure out a fix for the WS2812 pin in blink.c
```
  // RGB = solid green on boot
  ws2812_init(PICO_DEFAULT_WS2812_PIN);
  ws2812_put_rgb(0, 0x78, 0);
```
needed an ifdef/endif.
```
#ifdef PICO_DEFAULT_WS2812_POWER_PIN
  // RGB = solid green on boot
  ws2812_init(PICO_DEFAULT_WS2812_PIN);
  ws2812_put_rgb(0, 0x78, 0);
#endif
```
Now I'm trying to remember how I wired this up before.  Pretty sure I just followed the instructions and used
`cmake -DPICO_BOARD=pico -DCEC_PIN=11 ..` so that's what I'm going to try again today.

🍻

workingmanrob, 2025-05-09:
OK - finally got a build on the old original pico correctly speaking CEC to the TV.

Will pull out my multimeter in a bit and see if that gives any clues as to who's grounding who..

gkoh, 2025-05-09:
> OK - finally got a build on the old original pico correctly speaking CEC to the TV.

Good effort!
Happy to take (or make) a PR to support this better.

> Will pull out my multimeter in a bit and see if that gives any clues as to who's grounding who..

Right, it might not be GND continuity and just pulled low.
I'm starting to suspect the macbook port itself is the culprit, but we will see.

gkoh, 2025-05-09:
> PS - made some progress on the case for standard pico but I have also decided I'm going to chop the end of the pico off with a saw - https://www.hackster.io/news/phillip-burgess-hacks-a-raspberry-pi-pico-down-to-size-literally-sawing-off-the-bottom-quarter-d8478eecfb49 - so it will fit in the case

Now that is what I call a hack!

workingmanrob, 2025-05-09:
I just did a test with one probe on pin 13 and no other pin beeped continuity.  Checked to the shielded connector as well which did beep when I have a probe on pin 17.

If I use the same port on the macbook to connect my thunderbolt dock which then has an HDMI port on it - that works.  Obviously not comparing apples to apple but somehow the port can do the job.

Got a couple variations of mDP -> HDMI ordered so hopefully one of those just works and we can blame the el cheapo I have now.

gkoh, 2025-05-09:
> I just did a test with one probe on pin 13 and no other pin beeped continuity. Checked to the shielded connector as well which did beep when I have a probe on pin 17.

Interesting, good capture of information.

> If I use the same port on the macbook to connect my thunderbolt dock which then has an HDMI port on it - that works. Obviously not comparing apples to apple but somehow the port can do the job.

I guess worst case, that's an extremely not-el-cheapo mDP->HDMI adapter 😛

> Got a couple variations of mDP -> HDMI ordered so hopefully one of those just works and we can blame the el cheapo I have now.

Right, if they still don't work, I think the best bet is to cut the track.

workingmanrob, 2025-05-09:
Huzzah!!! 🥳 🎆 🥇 🍻 🍾

I bought 3 of these kits for 2 macbooks so I was willing to roll the dice and cut the track on the test board I am using today and magic immediately happened.

Used a precision flathead screwdriver as a scraping tool and that's all it took.

$7 doodad works a treat.  I'm going to leave this open for a day or two until the other adapters I have on order show up to see if this is a common issue.

Find the pin - mark with a red sharpie - slice and dice ferda win!

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

gkoh, 2025-05-09:
> Huzzah!!! 🥳 🎆 🥇 🍻 🍾

Nice!
That even looks reversible if ever the need might arise.

So, it's fairly clear that something is screwing with the CEC line and the answer is (controlled) violence 🙂

I'm glad we arrived at a workable outcome. Again, good effort and another data point.
When you're satisfied with the answer, I'll write up a wiki entry for the future traveller.

workingmanrob, 2025-05-09:
Yup.  Was trying to do as little damage as possible just in case it all fell apart.

But who doesn't love the get a bigger hammer fix??

Turns out my other setup that isn't a mac still works just fine with the trace cut so it seems to be a pretty safe mod.

Will leave this open until my other mDP adapters arrive and I can say if I need to do this everywhere or not.

...hopefully tomorrow 🤞

workingmanrob, 2025-05-16:
These new adapters must have taken the cross country pack mule shipping method but they finally got here today.

Quick test with the one pico where I cut the trace is working.

I wish I knew for sure if the other one I have has the trace cut or not but it also works.  I guess if it doesn't work, ya - get a bigger hammer.

Insten branded adapter that looks like this:

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

https://www.bestbuy.ca/en-ca/product/axgear-mini-displayport-thunderbolt-to-dvi-hdmi-vga-female-combo-adapter-m-f/12317245

Thanks for everything gkoh! 🍻

workingmanrob, 2025-05-16:
I got clever and used the other mDP adapter with the original seeed board setup and it did not work but the seeed board did work with the new mDP adapter. 👍

So I guess once again - if it doesn't work right away cut that trace - if it does work, have a beer. 🍺

gkoh, 2025-05-17:
> I got clever and used the other mDP adapter with the original seeed board setup and it did not work but the seeed board did work with the new mDP adapter. 👍
>
> So I guess once again - if it doesn't work right away cut that trace - if it does work, have a beer. 🍺

@workingmanrob Excellent conclusion!

Now you have me wondering if I 'just got lucky' with the DP->HDMI adapters I selected.
I might have to probe one to see if the CEC pin is connected ...

Closed 2025-04-28.

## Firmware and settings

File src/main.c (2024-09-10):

#include <stdio.h>

#include "FreeRTOS.h"
#include "queue.h"
#include "task.h"

#include "bsp/board.h"
#include "hardware/timer.h"
#include "pico/stdlib.h"

#include "hdmi-cec.h"
#include "usb_hid.h"

#define USBD_STACK_SIZE (512)
#define HID_STACK_SIZE (256)
#define CDC_STACK_SIZE (768)
#define BLINK_STACK_SIZE (128)
#define CEC_STACK_SIZE (512)
#define CEC_QUEUE_LENGTH (16)

void blink_task(void *param) {
  static uint32_t blink_delay = 1000;
  static bool state = true;

  while (true) {
    gpio_put(PICO_DEFAULT_LED_PIN, state);
    state = !state;
    vTaskDelay(pdMS_TO_TICKS(blink_delay));
  }
}

void cdc_task(void *param);

int main() {
  static StaticQueue_t xStaticCECQueue;
  static uint8_t storageCECQueue[CEC_QUEUE_LENGTH * sizeof(uint8_t)];

  static StackType_t stackBlink[BLINK_STACK_SIZE];
  static StackType_t stackCEC[CEC_STACK_SIZE];
  static StackType_t stackHID[HID_STACK_SIZE];
  static StackType_t stackCDC[CDC_STACK_SIZE];
  static StackType_t stackUSBD[USBD_STACK_SIZE];

  static StaticTask_t xBlinkTCB;
  static StaticTask_t xCECTCB;
  static StaticTask_t xHIDTCB;
  static StaticTask_t xUSBDTCB;
  static StaticTask_t xCDCTCB;

  static TaskHandle_t xBlinkTask;
  static TaskHandle_t xUSBDTask;
  static TaskHandle_t xHIDTask;
  static TaskHandle_t xCDCTask;

  stdio_init_all();
  board_init();

  alarm_pool_init_default();

  gpio_init(PICO_DEFAULT_LED_PIN);
  gpio_set_dir(PICO_DEFAULT_LED_PIN, GPIO_OUT);

  // HID key queue
  QueueHandle_t cec_q =
      xQueueCreateStatic(CEC_QUEUE_LENGTH, sizeof(uint8_t), &storageCECQueue[0], &xStaticCECQueue);

  xBlinkTask = xTaskCreateStatic(blink_task, "Blink Task", BLINK_STACK_SIZE, NULL, 1,
                                 &stackBlink[0], &xBlinkTCB);
  xCECTask = xTaskCreateStatic(cec_task, CEC_TASK_NAME, CEC_STACK_SIZE, &cec_q,
                               configMAX_PRIORITIES - 1, &stackCEC[0], &xCECTCB);
  xHIDTask = xTaskCreateStatic(hid_task, "hid", HID_STACK_SIZE, &cec_q, configMAX_PRIORITIES - 2,
                               &stackHID[0], &xHIDTCB);
  xUSBDTask = xTaskCreateStatic(usb_device_task, "usbd", USBD_STACK_SIZE, NULL,
                                configMAX_PRIORITIES - 3, &stackUSBD[0], &xUSBDTCB);
  xCDCTask = xTaskCreateStatic(cdc_task, "cdc", CDC_STACK_SIZE, NULL, configMAX_PRIORITIES - 4,
                               &stackCDC[0], &xCDCTCB);

  // bind CEC, blink, HID and CDC to core 0
  vTaskCoreAffinitySet(xCECTask, (1 << 0));
  vTaskCoreAffinitySet(xBlinkTask, (1 << 0));
  vTaskCoreAffinitySet(xHIDTask, (1 << 0));
  vTaskCoreAffinitySet(xCDCTask, (1 << 0));

  // bind USBD to core 1
  vTaskCoreAffinitySet(xUSBDTask, (1 << 1));

  vTaskStartScheduler();

  return 0;
}

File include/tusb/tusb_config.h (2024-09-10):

/*
 * The MIT License (MIT)
 *
 * Copyright (c) 2019 Ha Thach (tinyusb.org)
 *
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
 */

#ifndef _TUSB_CONFIG_H_
#define _TUSB_CONFIG_H_

#ifdef __cplusplus
extern "C" {
#endif

//--------------------------------------------------------------------+
// Board Specific Configuration
//--------------------------------------------------------------------+

// RHPort number used for device can be defined by board.mk, default to port 0
#ifndef BOARD_TUD_RHPORT
#define BOARD_TUD_RHPORT 0
#endif

// RHPort max operational speed can defined by board.mk
#ifndef BOARD_TUD_MAX_SPEED
#define BOARD_TUD_MAX_SPEED OPT_MODE_DEFAULT_SPEED
#endif

//--------------------------------------------------------------------
// COMMON CONFIGURATION
//--------------------------------------------------------------------

// defined by board.mk
#ifndef CFG_TUSB_MCU
#error CFG_TUSB_MCU must be defined
#endif

// Use FreeRTOS
#define CFG_TUSB_OS OPT_OS_FREERTOS

// Espressif IDF requires "freertos/" prefix in include path
#if TU_CHECK_MCU(OPT_MCU_ESP32S2, OPT_MCU_ESP32S3)
#define CFG_TUSB_OS_INC_PATH freertos /
#endif

// can be defined by compiler in DEBUG build
#ifndef CFG_TUSB_DEBUG
#define CFG_TUSB_DEBUG 0
#endif

// Enable Device stack
#define CFG_TUD_ENABLED 1

// Default is max speed that hardware controller could support with on-chip PHY
#define CFG_TUD_MAX_SPEED BOARD_TUD_MAX_SPEED

/* USB DMA on some MCUs can only access a specific SRAM region with restriction on alignment.
 * Tinyusb use follows macros to declare transferring memory so that they can be put
 * into those specific section.
 * e.g
 * - CFG_TUSB_MEM SECTION : __attribute__ (( section(".usb_ram") ))
 * - CFG_TUSB_MEM_ALIGN   : __attribute__ ((aligned(4)))
 */
#ifndef CFG_TUSB_MEM_SECTION
#define CFG_TUSB_MEM_SECTION
#endif

#ifndef CFG_TUSB_MEM_ALIGN
#define CFG_TUSB_MEM_ALIGN __attribute__((aligned(4)))
#endif

//--------------------------------------------------------------------
// DEVICE CONFIGURATION
//--------------------------------------------------------------------

#ifndef CFG_TUD_ENDPOINT0_SIZE
#define CFG_TUD_ENDPOINT0_SIZE 64
#endif

//------------- CLASS -------------//
#define CFG_TUD_HID 1
#define CFG_TUD_CDC 1
#define CFG_TUD_MSC 0
#define CFG_TUD_MIDI 0
#define CFG_TUD_VENDOR 0

// HID buffer size Should be sufficient to hold ID (if any) + Data
#define CFG_TUD_HID_EP_BUFSIZE 16

// CDC buffer sizes
#define CFG_TUD_CDC_RX_BUFSIZE (256)
#define CFG_TUD_CDC_TX_BUFSIZE (256)

#ifdef __cplusplus
}
#endif

#endif /* _TUSB_CONFIG_H_ */

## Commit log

2024-05-31 Minimally working version.
    Most useful HDMI commands mapped to Kodi keyboard shortcuts.
    Appears to be quite stable except for intermittent bug where system
    locks up and sends single key press infinitely.
    [hdmi-cec.c, main.c]
2024-06-01 Fix stack sizes for tasks.
    FreeRTOS stack sizes are specified as words (default 4 bytes for
    rp2040).
    This may have been the cause of the intermittent hangs.
    [hdmi-cec.c, main.c]
2024-06-04 Change to static allocation.
    Seems there's a deadlock bug in FreeRTOS heap3 on rp2040 (and heap4
    seems to just hang).
    Whilst here, tune the task stack sizes after some debug.
    [main.c, tusb_config.h]
2024-06-04 Another attempt to avoid random hang.
    Tweak stack sizes again.
    Give usbd all 4k stack on core 1.
    Move HID to core 0.
    Disable copy_to_ram for now.
    [main.c]
2024-06-07 Initial design for 3d printed housing.
    [pico-cec-base.scad, pico-cec-lib.scad, pico-cec-middle.scad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]
2024-06-07 Tweak various parameters.
    Send notify on abort (otherwise aborted CEC messages hang the system).
    Add necessary PICO_SYNC definitons to ensure FreeRTOS compatibility.
    This version seems to have fixed the various hangs.
    (Retweak the stack sizes based on high water mark values).
    [hdmi-cec.c, main.c]
2024-06-08 Make CEC pin configurable.
    Default configuration to Seeed Studio XIAO RP2040.
    Update OSD name to be 'Pico-CEC' to be clear.
2024-06-10 Tweak 3d model after prototype print.
    Increase various tolerances and add LED visibility.
    Also fix dependency in Makefile.
    [pico-cec-lib.scad, pico-cec.scad]
2024-06-10 Add FreeRTOS and pico-sdk as submodules.
2024-06-10 Freeze FreeRTOS-Kernel at V11.1.0.
    pico-sdk is already frozen at 1.5.1.
2024-06-16 Refactor CEC pin and address handling.
    Add configurable physical address.
2024-06-19 Initial cut of README.
2024-06-19 Tweak case tolerances.
    Increase M3 nut radius.
    Increase M3 bolt radius.
    Increase HDMI male width.
    [pico-cec-lib.scad]
2024-06-23 Add anonymous scope to fix declaration compiler error.
    Seems an older version of GCC and/or C standard doesn't like it.
    [hdmi-cec.c]
2024-06-23 Fix another compiler error.
    Hmm, this ubuntu cross-compiler is a bit pedantic.
    [main.c]
2024-06-23 Add STL export step to CI.
2024-07-03 Add semi-exploded STL for github rendering.
    [pico-cec.scad, pico-cec.stl]
2024-07-03 Adjust semi-exploded for piece clarity.
    [pico-cec.scad, pico-cec.stl]
2024-07-03 Update README.md
    Add link to exploded STL.
2024-07-22 Fix HDMI receive frame acknowledge timing. (#2)
    * Fix HDMI receive frame acknowledge timing.
    During the ACK bit, pull the line to low impedance at the start.
    The HDMI v1.3a specification requires low impedance from the follower no
    later than T1 == 0.35ms after start of bit.
    Reduce the idle time before frame transmission to 7 bit times.
    Whilst here, add additional responses:
    * broadcast physical address
    * broadcast device vendor ID
    * on routing change, broadcast image view on
    * Update real-world usage in README.
    [hdmi-cec.c]
2024-07-26 Implement EDID parsing to query physical address. (#4)
    * Implement EDID parsing to query physical address.
    Add I2C support for the HDMI DDC bus and query the upstream device for
    our HDMI physical address.
    This means the physical address is no longer hardcoded.
    Tested working with the following upstream devices:
    * Sharp TV
    * Sony TV
    * Denon Amp
    * Update README.md
    * Rename EDID to DDC for accuracy.
    Meanwhile, initialising the DDC lines seems to interfere with the video
    output of my x86 micro PC during boot.
    Modify the code to initialise and uninitialise the DDC bus only when we
    need to use it.
    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
    [hdmi-cec.c, hdmi-ddc.c, main.c]
2024-07-28 Fix support for Samsung TV. (#6)
    * Clean up FreeRTOS config header.
    * Add debug target.
    The debug target removes the USB HID binding and allows the Pico to send
    serial output to USB.
    NB. This build output tends to hang randomly, a lot, use at risk.
    * Refactor for CEC message handling.
    * Respond to 'Set Stream Path' message.
    Reply with an 'Active Source' broadcast when a 'Set Stream Path' message
    is received.
    * Issue a reset before reading.
    Looks like we should reset the DDC/EDID state before attempting a read.
    Do this by writing a 0 to the EDID address before trying to read any
    data back.
    [debug.c, hdmi-cec.c, hdmi-ddc.c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]
2024-07-29 Add basic schematic.
2024-07-29 Update schematic.
    Correct the schematic wiring pin for CEC.
2024-08-10 Add small delay to start of HDMI CEC task.
    The DDC/EDID traffic seems to disrupt the PC BIOS from determining valid
    display outputs during boot.
    This is likely due to pico-cec acting as another master on the I2C bus.
    Delay our DDC activity by 5000ms to allow the PC BIOS to "do it's thing"
    first.
2024-08-10 Add future point to README
    Perhaps port to ESP32?
    Would only really need to refactor the HDMI tx/rx interrupt/timer handling.
    Everything else is reasonably hardware agnostic.
2024-09-10 Initial support for USB composite device HID and CDC. (#13)
    * Initial support for USB composite device HID and CDC.
    Enable CDC so Pico-CEC appears as a connectable serial TTY device with
    baud rate 115200.
    Add tcli v0.2.5 as submodule.
    Add basic example CLI support via tcli for:
    * reboot [bootsel]
    * "reboot" -> reboot system
    * "reboot bootsel" -> reboot into bootloader
    * version
    * display version
    * Correct workflow variable substitution.
    Also remove stale include path.
    * Lower priority of CDC task.
    [main.c, tusb_config.h]
